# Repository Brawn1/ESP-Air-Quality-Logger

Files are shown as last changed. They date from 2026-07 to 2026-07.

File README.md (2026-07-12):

# Raumluft-Qualität-Messung (ESP32-S3-Zero)

CO₂-, Temperatur- und Feuchte-Messung mit dem **SCD30**, Anzeige auf einem
**0,96" OLED**, Status-Anzeige über eine **WS2812B-LED-Ampel**, Uhrzeit von
einer **DS3231-RTC** (mit NTP-Abgleich), Datenlogging auf **MicroSD** und einem
**WLAN-Webinterface**, dessen statische Dateien von der SD-Karte ausgeliefert
werden.

Die Firmware läuft unter **FreeRTOS** und verteilt die Arbeit auf beide Kerne
des ESP32-S3.

---

## Funktionen

- **Messung** von CO₂ / Temperatur / Luftfeuchte (SCD30, NDIR-Sensor)
- **OLED-Anzeige**: Uhrzeit, IP-Adresse, Messwerte groß + Ampel-Bewertung
- **LED-Ampel** (WS2812B): grün/orange/rot je nach CO₂, gut ablesbar quer durch den Raum
- **Weboberfläche** (responsiv, ohne externe Bibliotheken) mit Live-Werten und
  Verlaufsgraph (CO₂ / Temp / Feuchte umschaltbar)
- **Datenlogging** als Tages-CSV auf SD; Verlauf übersteht Neustart (`/history.json`)
- **Uhrzeit** aus DS3231-RTC, automatischer **NTP-Abgleich** bei WLAN-Verbindung
- **WLAN**: Verbindung ins Heimnetz, bei Fehlschlag eigener **Access-Point-Fallback**
- **Manuelle Kalibrierung** des SCD30 per BOOT-Taster (Forced Recalibration)

---

## Architektur (FreeRTOS, Dual-Core)

| Task | Kern | Prio | Aufgabe |
|---|:----:|:----:|---|
| `SensorTask`  |  1 |  3 | SCD30 lesen, Live-Wert/Verlauf/LED-Ampel, Logs auslösen, BOOT-Taster |
| `DisplayTask` |  1 |  2 | OLED zeichnen (Uhr, IP, Werte, Bewertung) |
| `LoggerTask`  |  1 |  2 | SD-Aufträge abarbeiten (CSV + `/history.json`) |
| `NetworkTask` |  0 |  1 | WLAN (STA + AP-Fallback), NTP, Webserver-Verwaltung |
| AsyncTCP |  0 |  – | Webserver-Requests (von der Bibliothek verwaltet) |

**Geteilte Busse werden per Mutex serialisiert** (nicht thread-safe):

- `g_i2cMutex` – **I²C** (SCD30 + DS3231), Zugriffe aus Tasks beider Kerne
- `g_spiMutex` – **SD-SPI-Bus** (Logger schreibt, Webserver liest)
- Daten-Mutex im `Data`-Modul – geteilter Zustand (Live-Wert + Verlaufs-Ringpuffer)
- Das **OLED** liegt auf einem **eigenen HSPI-Bus** (nur `DisplayTask`) → kein Mutex nötig

Datenfluss: `SensorTask` → (RAM-Ringpuffer + Queue) → `LoggerTask` (SD) /
`DisplayTask` (OLED) / Web-API (RAM).

---

## Verdrahtung (bitte gegen den Aufdruck deines Boards prüfen!)

### I²C-Bus – SCD30 und DS3231-RTC
| Signal | ESP32-S3-Zero |
|---|---|
| SDA | GPIO8 |
| SCL | GPIO9 |
| VCC | 3V3 (SCD30 verträgt 5V am VIN, Logik bleibt 3V3) |
| GND | GND |

> Beide I²C-Geräte an **denselben** SDA/SCL. Der SCD30 nutzt Clock-Stretching;
> deshalb ist der I²C-Takt bewusst auf 100 kHz gesetzt. Pull-ups (4,7 kΩ) sind
> auf den Modulen meist vorhanden.

### SPI-Bus 1 (FSPI) – nur MicroSD
| Signal | ESP32-S3-Zero |
|---|---|
| SCK | GPIO12 |
| MOSI | GPIO11 |
| MISO | GPIO13 |
| CS | GPIO10 |
| VCC / GND | 3V3 / GND  |

### SPI-Bus 2 (HSPI) – nur SSD1306-OLED (**eigener** Bus!)
SD und OLED **dürfen sich den SPI-Bus nicht teilen**: Die ESP32-`SD.h` nutzt den
IDF-`sdspi`-Treiber und belegt den SPI-Host exklusiv – ein zweites Gerät am
selben Bus bleibt stumm. Deshalb hat das OLED einen eigenen Bus.

| OLED-Pin (7-polige SPI-Platine) | ESP32-S3-Zero |
|---|---|
| D0 (CLK/SCK) | GPIO7 |
| D1 (DATA/MOSI) | GPIO1 |
| DC | GPIO4 |
| RES | GPIO6 |
| CS | GPIO5 |
| VCC / GND | 3V3 / GND |

**Alternative: I²C-OLED (4-polig)** – falls du ein SSD1306/SH1106 mit I²C statt SPI
hast, in `config.h` `#define OLED_USE_I2C 1` setzen. Das OLED läuft dann auf einem
**eigenen, zweiten I²C-Bus** (der ESP32-S3 hat zwei) — getrennt vom SCD30/RTC-Bus,
daher **kein Mutex nötig**. Praktisch: Es werden **dieselben Pins wie beim SPI-D0/D1**
verwendet, du musst also nichts umverdrahten:

| I²C-OLED-Pin | ESP32-S3-Zero | (= SPI-Pin) |
|---|---|---|
| SCL | GPIO7 | D0 |
| SDA | GPIO1 | D1 |
| VCC / GND | 3V3 / GND | – |

(Pins `PIN_OLED_I2C_SCL`/`PIN_OLED_I2C_SDA`, Adresse `OLED_I2C_ADDR` meist `0x3C`,
kein Reset-Pin nötig. Bus läuft mit 400 kHz.)

### WS2812B-Statusstreifen (CO₂-Ampel)
| Streifen | ESP32-S3-Zero |
|---|---|
| DIN (Pfeilrichtung beachten!) | GPIO2 (alt. GPIO1) |
| 5V | 5V |
| GND | GND |

> **GPIO3 meiden** (Strapping-Pin). Die LEDs (`NUM_STATUS_LEDS`, Standard 4) sind auf `LED_BRIGHTNESS = 30/255`
> gedimmt (Strom/Blendung); bei langen/hellen Streifen externes 5V-Netzteil mit
> gemeinsamer GND. Kurze Streifen laufen meist direkt mit dem 3,3-V-Datensignal,
> sonst Pegelwandler (3,3→5 V).

### BOOT-Taster
Der Onboard-**BOOT-Taster (GPIO0)** dient im Betrieb zum Auslösen der
Kalibrierung (siehe unten). Ruhezustand HIGH, gedrückt LOW.

### Pin-Übersicht
| Pin | Funktion | Pin | Funktion |
|-----|---|-----|---|
| GPIO8  | I²C SDA | GPIO7 | OLED SCK (D0) |
| GPIO9  | I²C SCL | GPIO1 | OLED MOSI (D1) |
| GPIO12 | SD SCK | GPIO4 | OLED DC |
| GPIO11 | SD MOSI | GPIO6 | OLED RES |
| GPIO13 | SD MISO | GPIO5 | OLED CS |
| GPIO10 | SD CS | GPIO2 | WS2812B DIN |
| GPIO0  | BOOT-Taster | | |

Alle Pins zentral in [`code/config.h`](code/config.h) änderbar.

---

## Projektstruktur

```
code/                 ← Arduino-Sketch (alle Dateien gehören dazu)
  code.ino            Setup + FreeRTOS-Tasks
  config.h            Pins, Intervalle, Schwellen, Task-Konfiguration
  Sync.*              geteilter SPI-Bus + Mutexe (I²C / SPI)
  Data.*              thread-sicherer Ringpuffer + Live-Wert + Status
  Sensor.*            SCD30 (Sensirion I2C SCD30)
  AppTime.*           DS3231-RTC + NTP
  Storage.*           SD: config.json, CSV, history.json, Datei-Auslieferung
  Display.*           OLED (SSD1306 / SH1106 umschaltbar)
  Led.*               WS2812B-CO₂-Ampel
  WebNet.*            WLAN (STA/AP), NTP-Start, Async-Webserver
sd_card/              ← Inhalt auf die SD-Karten-Wurzel kopieren
  config.json         WLAN + Einstellungen
  www/                Weboberfläche (index.html, style.css, app.js)
README.md
```

---

## Benötigte Arduino-Bibliotheken

Über den **Bibliotheksverwalter** installieren:

- **Sensirion I2C SCD30** (zieht *Sensirion Core* mit)
- **Adafruit SSD1306** + **Adafruit GFX Library**
- **Adafruit SH110X** (nur nötig, wenn `OLED_USE_SH1106 = 1`)
- **RTClib** (Adafruit)
- **Adafruit NeoPixel**
- **ArduinoJson** (v7)
- **Async TCP** *(Maintainer: ESP32Async, v3.4.x)*
- **ESP Async WebServer** *(Maintainer: ESP32Async, v3.11.x)*

> ⚠️ **Richtigen Async-Fork wählen!** Es gibt mehrere gleichnamige Bibliotheken.
> Es funktionieren **nur** die von **ESP32Async** gepflegten, exakt benannt
> **„Async TCP"** und **„ESP Async WebServer"** (mit Leerzeichen). Die Varianten
> `AsyncTCP` (dvarrel) bzw. `ESPAsyncWebServer` (lacamera) sind mit ESP32-Core 3.x
> **nicht** kompatibel (Compile-Fehler in `WiFiGeneric.h`).

`WiFi`, `SD`, `SPI`, `Wire`, `ESPmDNS` sind Teil des ESP32-Arduino-Cores.

### Board / Core
- Boardverwalter-URL für ESP32 hinzufügen, **esp32 by Espressif** (Core **3.x**) installieren.
- Board: **ESP32S3 Dev Module** (oder „Waveshare ESP32-S3-Zero", falls vorhanden).
- **PSRAM**: „QSPI/OPI PSRAM" aktivieren, falls dein Modul PSRAM hat (sonst „Disabled").
- **USB CDC On Boot: Enabled** (für die serielle Ausgabe über USB-C).
- **Partition Scheme: „Huge APP (3MB No OTA/1MB SPIFFS)"** – reichlich Reserve
  (SPIFFS wird nicht gebraucht, alles liegt auf der SD).

---

## Einrichtung

1. **SD-Karte** (FAT32) vorbereiten und den **Inhalt** von [`sd_card/`](sd_card/)
   in das **Wurzelverzeichnis** kopieren:
   ```
   SD-Root/
     config.json
     www/
       index.html
       style.css
       app.js
   ```
2. In `config.json` **WLAN-Zugangsdaten** und ggf. Zeitzone/Intervalle eintragen.
   - Leeres `wifi_ssid` → Gerät startet direkt im **Access-Point-Modus**.
   - Fehlschlagende WLAN-Verbindung → automatischer AP `Raumluft-Sensor`
     (Passwort `raumluft1234`).
3. Sketch [`code/code.ino`](code/code.ino) in der Arduino IDE öffnen, Board wählen,
   **hochladen**.
4. Serielle Konsole (115200 Baud) zeigt die zugewiesene **IP-Adresse**.
   Aufruf im Browser: `http://<IP>` oder `http://raumluft.local`.

---

## Konfiguration (`config.json`)

Alle Werte werden **zur Laufzeit** von der SD geladen; die Konstanten in
`config.h` sind nur die Fallback-Defaults, falls die Datei fehlt.

| Schlüssel | Standard | Bedeutung |
|---|---|---|
| `wifi_ssid` | – | WLAN-Name (leer = direkt AP-Modus) |
| `wifi_pass` | – | WLAN-Passwort |
| `ap_ssid` | `Raumluft-Sensor` | Name des Fallback-Access-Points |
| `ap_pass` | `raumluft1234` | AP-Passwort (≥8 Zeichen, "" = offen) |
| `hostname` | `raumluft` | mDNS-Name → `http://raumluft.local` |
| `ntp_server` | `pool.ntp.org` | NTP-Server |
| `tz` | `CET-1CEST,M3.5.0,M10.5.0/3` | Zeitzone (POSIX-TZ) |
| `scd30_interval_s` | `5` | Mess-Takt des Sensors (2…1800 s) |
| `history_interval_s` | `90` | Graph-Punkt + `/history.json` schreiben |
| `log_interval_s` | `300` | CSV-Archiv-Takt (s) |
| `temp_offset_c` | `3.0` | Temperatur-Offset (°C), per Software abgezogen: Anzeige = Messwert − Offset (auch negativ) |

> ⚠️ **JSON-Schlüssel sind Groß-/Kleinschreibung-sensitiv** – exakt so schreiben,
> sonst wird der Eintrag still ignoriert und der Standardwert genutzt.

---

## Bedienung

### OLED-Anzeige
```
12:34:56              WiFi   ← Uhrzeit + Netz-Kennung (WiFi/AP)
192.168.1.42     kein SD     ← IP (STA/AP); rechts "kein SD" falls Karte fehlt
612          ppm             ← CO₂ groß
T 22.8C  H 45%               ← Temperatur / Feuchte
OK                           ← Bewertung: OK / Lueften empf. / Raum lueften
```

Fehlt/defekt die SD-Karte, zeigt das Display beim Start einen Warn-Screen
(„KEINE SD-KARTE") und dauerhaft den Hinweis **`kein SD`** neben der IP. Die
Karte wird **im Betrieb überwacht** (alle ~5 s): Herausziehen wird erkannt und
angezeigt, Wiedereinstecken automatisch übernommen. (Ohne SD gibt es kein
Webinterface, da dessen Dateien auf der Karte liegen.)

### LED-Ampel (WS2812B)
Alle LEDs (`NUM_STATUS_LEDS`, Standard 4) leuchten gemeinsam in der Ampelfarbe des
aktuellen CO₂-Werts:
**grün ≤ 1000 (OK) → orange ≤ 1400 (Lüften empfohlen) → rot > 1400 (Raum lüften).**
Kein Messwert → blau.

### Weboberfläche
Live-Werte (Polling), umschaltbarer Verlaufsgraph (CO₂ / Temp / Feuchte) und
Statusleiste (WLAN, SD, RTC/NTP). Die statischen Dateien werden im Browser
gecacht – nach dem ersten Laden werden bei Reload nur noch die kleinen
`/api/*`-Aufrufe geholt (schont Verbindungen).

---

## Web-API

| Endpoint | Antwort |
|---|---|
| `GET /api/current` | aktueller Messwert + Status (JSON) |
| `GET /api/history` | letzte 30 Verlaufspunkte (JSON, aus RAM) |
| alles andere | statische Datei aus `/www` auf der SD |

Beispiel `/api/current`:
```json
{"time":1751385600,"co2":612,"temp":22.80,"hum":47.0,"valid":true,
 "wifi":true,"ap":false,"ip":"192.168.1.42","ssid":"MeinWLAN",
 "rtc":true,"sd":true,"synced":true}
```

---

## Dateien auf der SD-Karte

| Pfad | Inhalt |
|---|---|
| `/config.json` | Konfiguration (s. o.) |
| `/www/…` | Weboberfläche (HTML/CSS/JS) |
| `/history.json` | letzte 30 Verlaufspunkte – wird alle `history_interval_s` geschrieben und beim Booten geladen (Graph sofort gefüllt) |
| `/logs/JJJJ-MM-TT.csv` | Langzeit-Archiv, eine Zeile je `log_interval_s` |

CSV-Format:
```
epoch_utc,datetime_local,co2_ppm,temp_c,hum_pct
```

---

## Kalibrierung (BOOT-Taster)

Der SCD30 lässt sich per **Forced Recalibration (FRC)** über den **BOOT-Taster
(GPIO0)** auf einen Frischluft-Referenzwert setzen (`CO2_CALIBRATION_PPM`,
Standard **420 ppm** ≈ heutige Außenluft).

1. Gerät im Betrieb an **gut durchmischte Frischluft** bringen (draußen / offenes
   Fenster mit Durchzug), Sensor **frei halten, nicht bodennah**.
2. **~2 Minuten** messen lassen, damit der Wert stabil ist.
3. **BOOT-Taster ca. 3 Sekunden halten** (`CAL_HOLD_MS`).
4. Bestätigung: LED-Streifen blinkt **3× grün** (und OLED-Meldung, falls aktiv).

**Wichtig:**
- Taster nur **im Betrieb** drücken – *nicht* beim Reset/Einschalten (sonst geht
  der ESP32 in den Download-Modus).
- **Abends auf dem Land ungünstig:** windstille Abende stauen bodennah CO₂ →
  besser tagsüber bei etwas Wind.
- Eine falsche Referenz verzieht die Werte dauerhaft, lässt sich aber jederzeit
  mit besserer Frischluft neu kalibrieren.

> Alternativ gibt es die automatische Selbstkalibrierung (ASC) des SCD30. Sie ist
> **aus**; bei Dauerbetrieb in regelmäßig gelüfteten Räumen kann sie in
> `sensorBegin()` per `activateAutoCalibration(1)` eingeschaltet werden.

---

## Hinweise / Tuning / Troubleshooting

- **OLED bleibt dunkel?** SD und OLED **nicht** an denselben SPI-Bus hängen (s. o.).
  Bleibt es auf dem eigenen HSPI-Bus *immer noch* leer, ist es evtl. ein
  **SH1106**-Controller statt SSD1306. Umschalter in `config.h`:
  ```c
  #define OLED_USE_SH1106 1   // 0 = SSD1306, 1 = SH1106 (Adafruit SH110X)
  ```
- **OLED zu dunkel / ungleichmäßig?** Kontrast steht bereits auf `OLED_CONTRAST = 255`,
  Precharge (`OLED_PRECHARGE`, SSD1306) lässt sich Richtung `0xFF` anheben. Eine
  weiche Rand-Abdunklung ist meist eine Eigenschaft des Panels selbst.
- **Verlauf übersteht Neustart** über `/history.json` (Laden beim Booten). Die
  laufende `/api/history` bleibt reines RAM (schnell), das CSV ist das Archiv.
- **WLAN nur 2,4 GHz:** Der ESP32 verbindet sich nicht mit 5-GHz-Netzen. Klappt
  die STA-Verbindung nicht, läuft das Gerät im AP-Modus (`192.168.4.1`), und ohne
  Internet gibt es keinen NTP-Sync (Zeit dann rein aus der DS3231).
- **Webserver reagiert nach mehreren Verbindungen nicht mehr?** Diagnose über die
  serielle Heap-Ausgabe (alle 30 s): fällt „Heap frei" stetig → Speicher; bleibt
  er stabil → Verbindungs-Slots. Das Caching der statischen Dateien reduziert die
  Last bereits deutlich; bei Bedarf Poll-Intervall in `app.js` strecken.
- **SD-Takt:** Bei instabilen Karten in `Storage.cpp` von `20000000` auf `4000000`
  (4 MHz) reduzieren.
- **RTC erstmalig stellen:** passiert automatisch beim ersten erfolgreichen
  NTP-Sync. Ohne Internet läuft die Zeit rein aus der DS3231.

### Modul-Namen (Fallstricke)
Das Netzwerkmodul heißt bewusst `WebNet.*` (nicht `Network.*`) und die
LED-Konstante `PIN_STATUS_LED` (nicht `PIN_RGB_LED`) – beide Namen sind im
ESP32-Core/S3-Variant bereits belegt und würden sonst Compile-Fehler auslösen.

---

## Lizenz

Copyright (C) 2026 Guenter Bailey

Dieses Projekt steht unter der **GNU Affero General Public License v3.0**
(AGPL-3.0) – siehe [LICENSE](LICENSE).

> Dieses Programm ist freie Software: Sie können es unter den Bedingungen der
> AGPL-3.0 weitergeben und/oder verändern. Es wird **ohne jede Gewährleistung**
> bereitgestellt; siehe die Lizenz für Details. Sie sollten eine Kopie der Lizenz
> zusammen mit diesem Programm erhalten haben. Falls nicht, siehe
> <https://www.gnu.org/licenses/>.

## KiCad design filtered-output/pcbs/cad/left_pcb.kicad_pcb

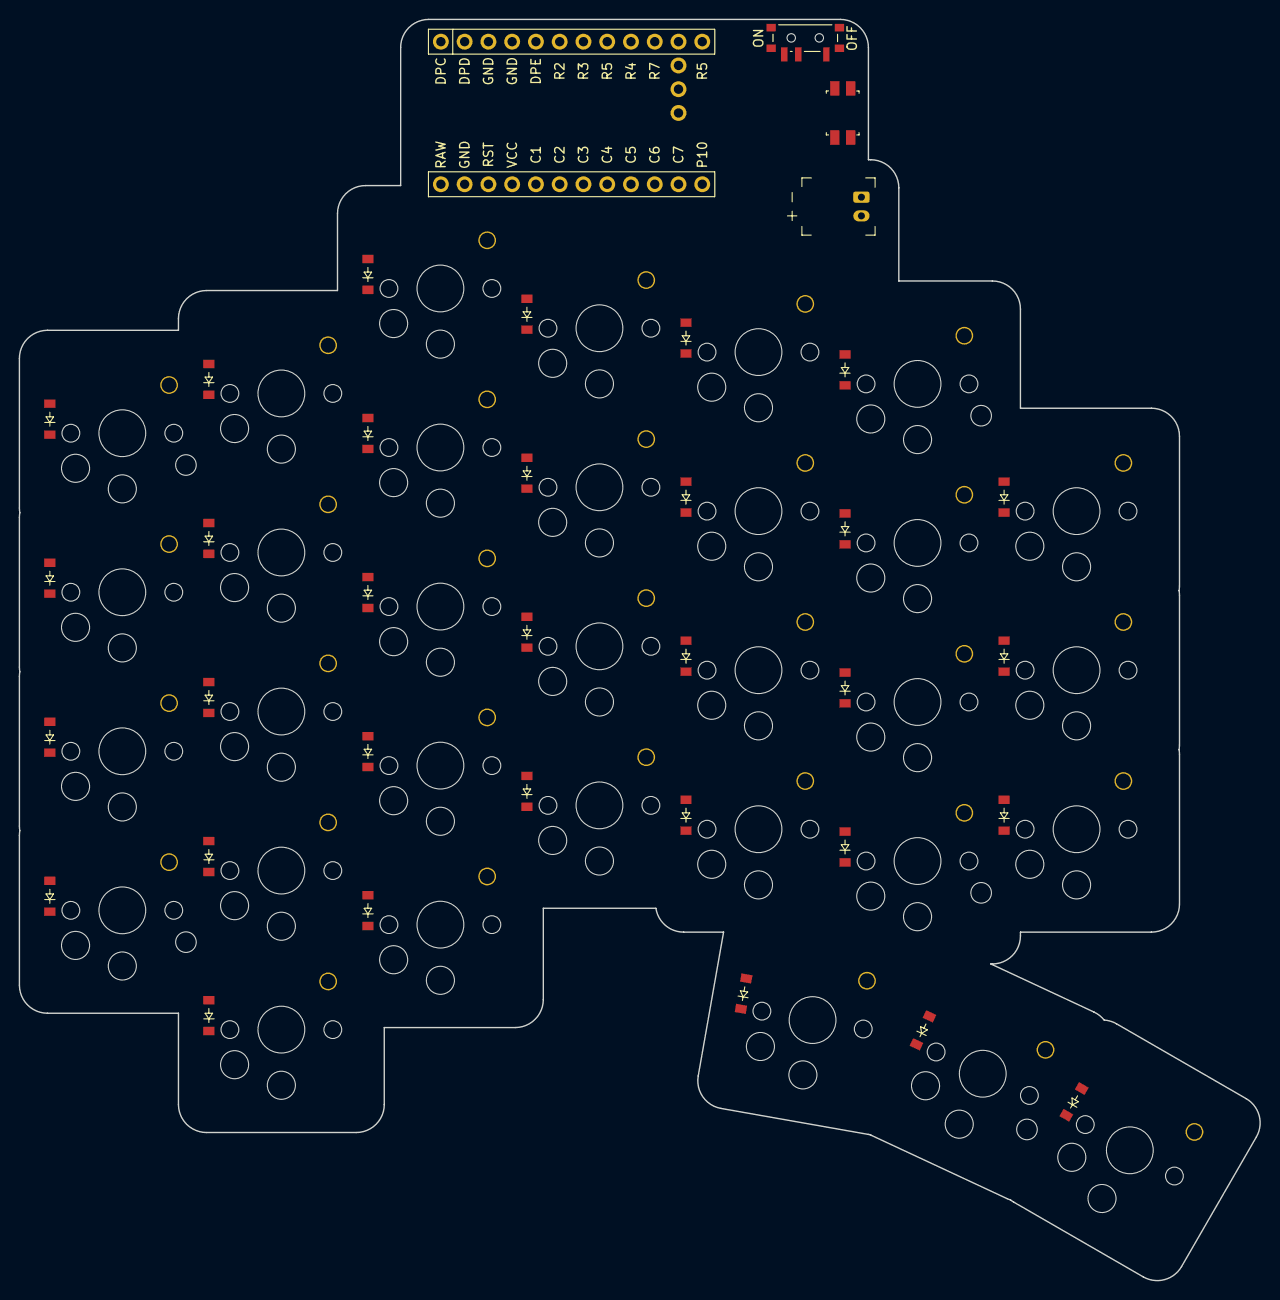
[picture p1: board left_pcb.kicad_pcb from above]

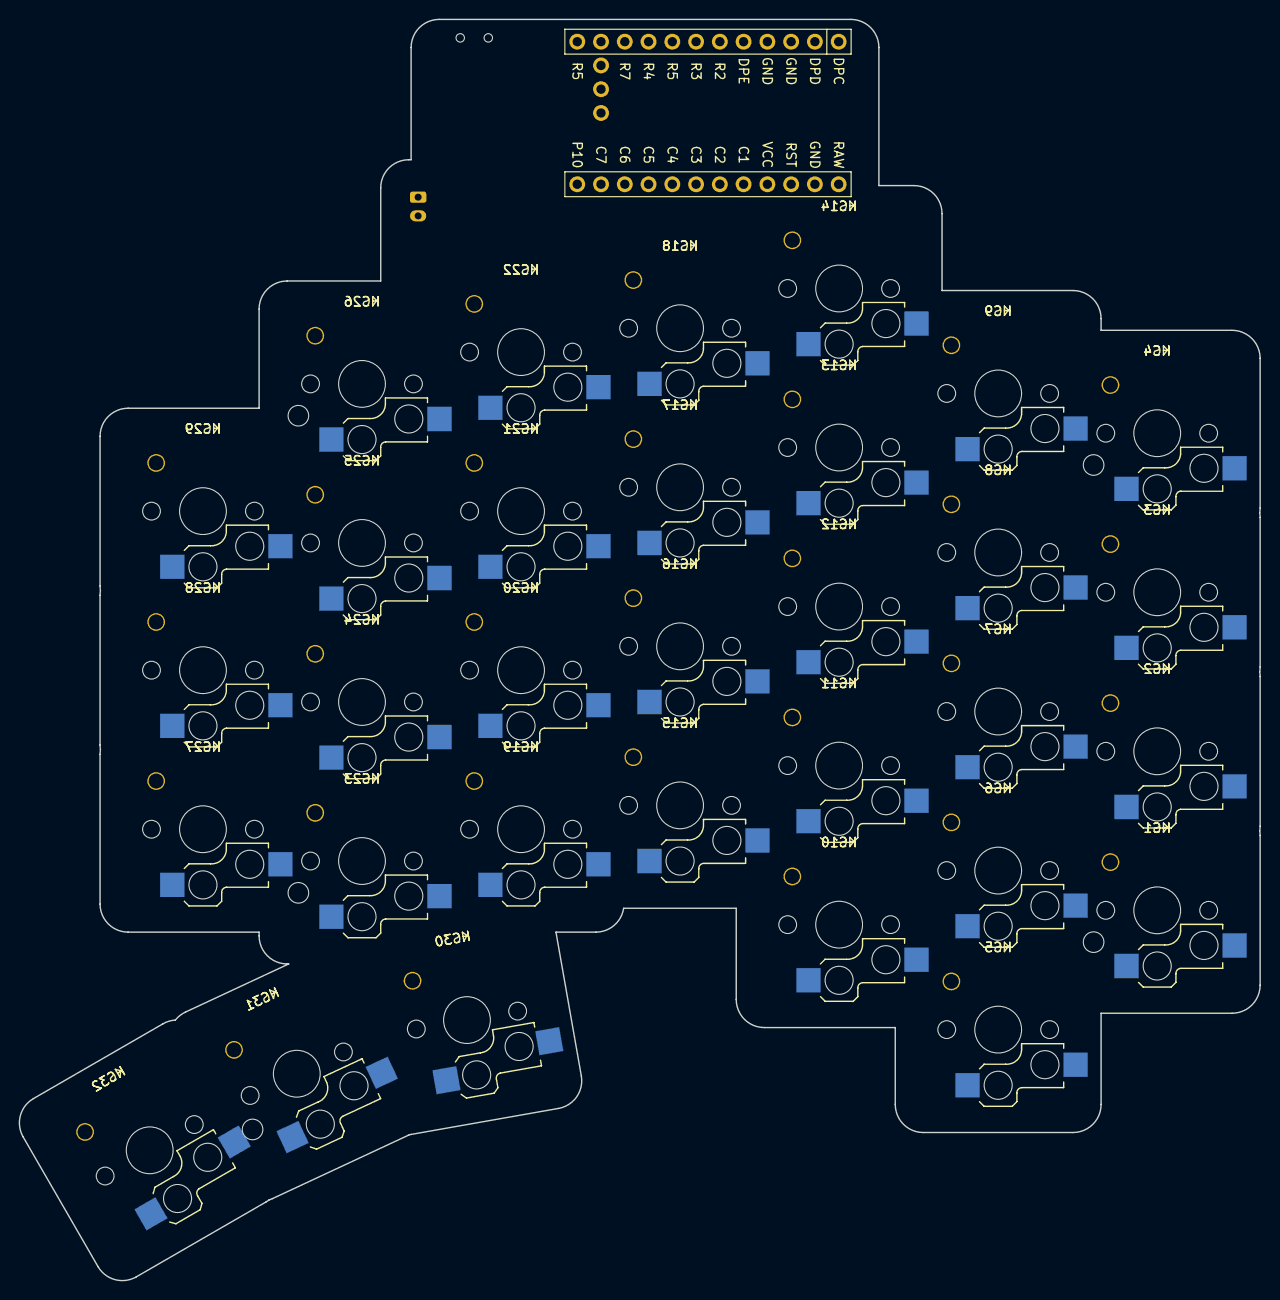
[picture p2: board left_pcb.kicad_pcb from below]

Board: 2 copper layers, 132.6 x 134.8 mm, 154 parts (96 on the bottom side), 48 nets, no tracks yet.

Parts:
D1, D2, D3, D4, D5, D6, D7, D8, D9, D10, D11, D12, D13, D14, D15, D16, D17, D18, D19, D20, D21, D22, D23, D24, D25, D26, D27, D28, D29, D30, D31, D32: diode_tht_sod123
H1, H2: header-preview_nano
HS1, HS2, HS3, HS4, HS5, HS6, HS7, HS8, HS9, HS10, HS11, HS12, HS13, HS14, HS15, HS16, HS17, HS18, HS19, HS20, HS21, HS22, HS23, HS24, HS25, HS26, HS27, HS28, HS29, HS30, HS31, HS32: hs-socket-fab-preview_choc_v1_v2
JST1: battery_connector_jst_ph_2
KC1, KC2, KC3, KC4, KC5, KC6, KC7, KC8, KC9, KC10, KC11, KC12, KC13, KC14, KC15, KC16, KC17, KC18, KC19, KC20, KC21, KC22, KC23, KC24, KC25, KC26, KC27, KC28, KC29, KC30, KC31, KC32: keycap-fab-preview_choc_v1_v2
MCU1: mcu_nice_nano
MH1, MH2, MH3, MH4, MH5: mounting_hole_npth
PWR1: power_switch_smd_side
RST1: reset_switch_smd_side
S1, S2, S3, S4, S5, S6, S7, S8, S9, S10, S11, S12, S13, S14, S15, S16, S17, S18, S19, S20, S21, S22, S23, S24, S25, S26, S27, S28, S29, S30, S31, S32: choc_v1_v2
SC1, SC2, SC3, SC4, SC5: screw-preview-top
SC6, SC7, SC8, SC9, SC10: screw-preview-bottom
ST1, ST2, ST3, ST4, ST5: standoff-preview

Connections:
BAT_P: JST1.2, PWR1.3
C1: MCU1.20, S1.2, S2.2, S3.2, S4.2
C2: MCU1.19, S5.2, S6.2, S7.2, S8.2, S9.2
C3: MCU1.18, S10.2, S11.2, S12.2, S13.2, S14.2
C4: MCU1.17, S15.2, S16.2, S17.2, S18.2
C5: MCU1.16, S19.2, S20.2, S21.2, S22.2, S30.2
C6: MCU1.15, S23.2, S24.2, S25.2, S26.2, S31.2
C7: MCU1.14, S27.2, S28.2, S29.2, S32.2
GND: JST1.1, MCU1.3, MCU1.4, MCU1.23, RST1.1, RST1.3
R1: D4.1, D9.1, D14.1, D18.1, D22.1, D26.1
R2: D3.1, D8.1, D13.1, D17.1, D21.1, D25.1, D29.1, MCU1.6
R3: D2.1, D7.1, D12.1, D16.1, D20.1, D24.1, D28.1, MCU1.7
R4: D1.1, D6.1, D11.1, D15.1, D19.1, D23.1, D27.1, MCU1.9
R5: D5.1, D10.1, D30.1, D31.1, D32.1, MCU1.8, MCU1.12
RAW: MCU1.24, PWR1.2
RST: MCU1.22, RST1.2, RST1.4
col1_row1: D4.2, S4.1
col1_row2: D3.2, S3.1
col1_row3: D2.2, S2.1
col1_row4: D1.2, S1.1
col1_thumb_row_1: D30.2, S30.1
col2_row1: D9.2, S9.1
col2_row2: D8.2, S8.1
col2_row3: D7.2, S7.1
col2_row4: D6.2, S6.1
col2_row5: D5.2, S5.1
col2_thumb_row_1: D31.2, S31.1
col3_row1: D14.2, S14.1
col3_row2: D13.2, S13.1
col3_row3: D12.2, S12.1
col3_row4: D11.2, S11.1
col3_row5: D10.2, S10.1
col3_thumb_row_1: D32.2, S32.1
col4_row1: D18.2, S18.1
col4_row2: D17.2, S17.1
col4_row3: D16.2, S16.1
col4_row4: D15.2, S15.1
col5_row1: D22.2, S22.1
col5_row2: D21.2, S21.1
col5_row3: D20.2, S20.1
col5_row4: D19.2, S19.1
col6_row1: D26.2, S26.1
col6_row2: D25.2, S25.1
col6_row3: D24.2, S24.1
col6_row4: D23.2, S23.1
col7_row2: D29.2, S29.1
col7_row3: D28.2, S28.1
col7_row4: D27.2, S27.1

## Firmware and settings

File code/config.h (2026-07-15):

// ============================================================================
//  config.h  -  Zentrale Konfiguration & gemeinsame Datentypen
//  Projekt: Raumluft-Qualitaet-Messung (ESP32-S3-Zero)
// ============================================================================
#pragma once
#include <Arduino.h>

// ----------------------------------------------------------------------------
//  PIN-BELEGUNG  (ESP32-S3-Zero / Waveshare)
//  -> Bitte gegen den Aufdruck deines Boards pruefen und ggf. anpassen.
//
//  I2C-Bus (gemeinsam fuer SCD30-Sensor und DS3231-RTC):
//     SDA = GPIO8      SCL = GPIO9
//
//  SPI-Bus 1 (FSPI) - NUR MicroSD:
//     SCK = GPIO12   MOSI = GPIO11   MISO = GPIO13   SD-CS = GPIO10
//  SPI-Bus 2 (HSPI) - NUR SSD1306-OLED (eigener Bus, damit kein Konflikt mit
//                     dem IDF-sdspi-Treiber der SD-Karte entsteht):
//     SCK = GPIO7   MOSI = GPIO1   DC = GPIO4   RST = GPIO6   CS = GPIO5
//     (OLED hat kein MISO - Display ist reines Schreibziel)
//
//  WS2812B-Statusstreifen (CO2-Balken), Daten-Pin (DIN): GPIO2
//  (GPIO1 oder GPIO2 verwenden; GPIO3 meiden = Strapping-Pin.
//   Hinweis: NICHT 'PIN_RGB_LED' verwenden - dieser Name ist im S3-Variant
//   bereits als Makro belegt.)
// ----------------------------------------------------------------------------
static const int PIN_I2C_SDA = 8;
static const int PIN_I2C_SCL = 9;

// SD-Bus (FSPI)
static const int PIN_SPI_MOSI = 11;
static const int PIN_SPI_SCK  = 12;
static const int PIN_SPI_MISO = 13;
static const int PIN_SD_CS    = 10;

// SD-SPI-Takt in Hz. Niedriger = robuster (v.a. bei grossen SDXC-Karten / langen
// Leitungen). 4 MHz ist sehr zuverlaessig; unsere Datenmengen sind winzig.
static const uint32_t SD_SPI_HZ = 4000000;

// OLED-Bus (HSPI, eigener Bus)
static const int PIN_OLED_SCK  = 7;
static const int PIN_OLED_MOSI = 1;
static const int PIN_OLED_DC   = 4;
static const int PIN_OLED_RST  = 6;
static const int PIN_OLED_CS   = 5;

static const int PIN_STATUS_LED = 2;    // WS2812B-Streifen DIN; -1 = deaktiviert

static const int PIN_BOOT_BUTTON = 0;   // Onboard-BOOT-Taster (GPIO0, active low)

// ----------------------------------------------------------------------------
//  OLED-Geometrie (0,96" SSD1306)
// ----------------------------------------------------------------------------
static const int OLED_WIDTH  = 128;
static const int OLED_HEIGHT = 64;

// OLED-Controller waehlen:  0 = SSD1306,  1 = SH1106 (Adafruit SH110X)
// -> Zum Testen des anderen Display-Typs einfach umschalten und neu flashen.
#define OLED_USE_SH1106 0

// OLED-Anbindung waehlen:  0 = SPI (7-polig, eigener HSPI-Bus),
//                          1 = I2C auf EIGENEM 2. Bus (Wire1) an den Display-Pins
// Bei I2C wird ein separater I2C-Bus genutzt (NICHT der SCD30/RTC-Bus) -> keine
// Umverdrahtung noetig, kein Mutex. Die Display-Pins bleiben GPIO7/GPIO1:
//   GPIO7 (= D0 am Display) = SCL,  GPIO1 (= D1 am Display) = SDA
#define OLED_USE_I2C 1

static const uint8_t OLED_I2C_ADDR   = 0x3C;   // meist 0x3C, manche Module 0x3D
static const int     PIN_OLED_I2C_SCL = 7;     // = D0 am Display (GPIO7)
static const int     PIN_OLED_I2C_SDA = 1;     // = D1 am Display (GPIO1)

// Helligkeit/Kontrast des OLED (0..255). 255 = maximal hell.
static const uint8_t OLED_CONTRAST = 100;

// Precharge-Periode (Befehl 0xD9): High-Nibble = Phase 2, Low-Nibble = Phase 1
// (je 1..15 Takte). Laenger = heller/gleichmaessiger. Adafruit-Default 0xF1.
// Zum Aufhellen v.a. das Low-Nibble (Phase 1) anheben, bis max. 0xFF.
static const uint8_t OLED_PRECHARGE = 0xF1;

// ----------------------------------------------------------------------------
//  Mess- & Logintervalle
// ----------------------------------------------------------------------------
// Drei getrennte Kadenzen (alle zur Laufzeit ueber config.json ueberschreibbar):
static const uint32_t SCD30_INTERVAL_S   = 8;    // Sensor-Messintervall (2..1800 s)
static const uint32_t HISTORY_INTERVAL_S = 90;   // Graph-Punkt + /history.json schreiben
static const uint32_t LOG_INTERVAL_S     = 300;  // CSV-Archiv (5 min)

// Anzahl der Punkte im Verlaufsgraphen (RAM-Ringpuffer + /history.json).
static const int HISTORY_LEN = 30;

// ----------------------------------------------------------------------------
//  CO2-Ampel-Schwellen (ppm)
// ----------------------------------------------------------------------------
static const uint16_t CO2_GOOD_MAX    = 1000;   // <= gruen (OK)
static const uint16_t CO2_MEDIUM_MAX  = 1400;   // <= orange (Lueften empf.), darueber rot

// ----------------------------------------------------------------------------
//  Manuelle Kalibrierung (Forced Recalibration) per BOOT-Taster
// ----------------------------------------------------------------------------
static const uint16_t CO2_CALIBRATION_PPM = 420;    // Referenz = Frischluft (akt. Atmosphaere ~420 ppm)
static const uint32_t CAL_HOLD_MS         = 3000;   // Taster so lange halten

// ----------------------------------------------------------------------------
//  Temperatur-Offset (SCD30 misst durch Eigenerwaermung zu hoch)
//  Wird per Software vom Messwert abgezogen: angezeigt = gemessen - Offset.
//  Positiv = Anzeige senken (Normalfall), negativ = anheben moeglich.
// ----------------------------------------------------------------------------
static const float TEMP_OFFSET_C = 3.0f;

// ----------------------------------------------------------------------------
//  WS2812B-Statusstreifen als CO2-Ampel (alle LEDs = Ampelfarbe)
// ----------------------------------------------------------------------------
static const int      NUM_STATUS_LEDS = 1;      // Anzahl LEDs am Streifen (bei neuem Streifen hier erhoehen)
static const uint8_t  LED_BRIGHTNESS  = 30;     // 0..255 (gedimmt, spart Strom)

// ----------------------------------------------------------------------------
//  WLAN / Netzwerk  (Standardwerte; werden von /config.json auf der SD ueberschrieben)
// ----------------------------------------------------------------------------
#define DEFAULT_WIFI_SSID     ""            // dein Heim-WLAN
#define DEFAULT_WIFI_PASS     ""
#define DEFAULT_AP_SSID       "Raumluft-Sensor"
#define DEFAULT_AP_PASS       "raumluft1234"  // min. 8 Zeichen (WPA2), "" = offen
#define DEFAULT_HOSTNAME      "raumluft"

// NTP / Zeitzone (Standard: Mitteleuropa mit Sommerzeit)
#define DEFAULT_NTP_SERVER    "pool.ntp.org"
#define DEFAULT_TZ            "CET-1CEST,M3.5.0,M10.5.0/3"

// ----------------------------------------------------------------------------
//  Gemeinsamer Datentyp fuer einen Messpunkt
// ----------------------------------------------------------------------------
struct Sample {
  uint32_t epoch;   // Unix-Zeit (Sekunden) laut RTC
  float    co2;     // ppm
  float    temp;    // Grad Celsius
  float    hum;     // % relative Feuchte
  uint32_t heap;    // freier Heap (Bytes) zum Messzeitpunkt - Diagnose
  bool     valid;
};

// ----------------------------------------------------------------------------
//  Laufzeit-Konfiguration (aus /config.json geladen)
// ----------------------------------------------------------------------------
struct AppConfig {
  String wifiSsid   = DEFAULT_WIFI_SSID;
  String wifiPass   = DEFAULT_WIFI_PASS;
  String apSsid     = DEFAULT_AP_SSID;
  String apPass     = DEFAULT_AP_PASS;
  String hostname   = DEFAULT_HOSTNAME;
  String ntpServer  = DEFAULT_NTP_SERVER;
  String tz         = DEFAULT_TZ;
  uint32_t logIntervalS     = LOG_INTERVAL_S;      // CSV-Archiv-Takt (s)
  uint32_t historyIntervalS = HISTORY_INTERVAL_S;  // Graph-/History-Takt (s)
  uint32_t scd30IntervalS   = SCD30_INTERVAL_S;    // SCD30-Mess-Takt (s, 2..1800)
  float    tempOffsetC      = TEMP_OFFSET_C;       // Temperatur-Offset (Grad C)
};

extern AppConfig g_cfg;

// ----------------------------------------------------------------------------
//  FreeRTOS-Task-Konfiguration
//  ESP32-S3 = Dual-Core:  Core 0 = Netzwerk, Core 1 = Messung/Anzeige
// ----------------------------------------------------------------------------
static const BaseType_t CORE_MEASURE = 1;   // Messkern
static const BaseType_t CORE_NETWORK = 0;   // Netzwerkkern

// Stackgroessen (Bytes) und Prioritaeten (hoeher = wichtiger, IDLE = 0)
static const uint32_t STACK_SENSOR  = 4096;
static const uint32_t STACK_DISPLAY = 4096;
static const uint32_t STACK_LOGGER  = 4096;
static const uint32_t STACK_NETWORK = 8192;

static const UBaseType_t PRIO_SENSOR  = 3;
static const UBaseType_t PRIO_DISPLAY = 2;
static const UBaseType_t PRIO_LOGGER  = 2;
static const UBaseType_t PRIO_NETWORK = 1;

// Laenge der Logger-Queue (gepufferte Samples, falls SD kurz blockiert)
static const uint32_t LOGGER_QUEUE_LEN = 8;

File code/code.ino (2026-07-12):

// ============================================================================
//  Raumluft-Qualitaet-Messung  -  ESP32-S3-Zero
//
//  Sensor:   SCD30  (CO2 / Temperatur / Feuchte, I2C - Sensirion-Lib)
//  Anzeige:  SSD1306 0,96" OLED (SPI) - Uhrzeit, IP, CO2/Temp/Feuchte + Bewertung
//  Uhr:      DS3231 RTC (I2C) + NTP-Synchronisation
//  Speicher: MicroSD (SPI) - CSV-Archiv, /history.json, statische Webdateien
//  Netzwerk: WLAN (STA mit AP-Fallback) + Async-Webserver
//
//  Architektur (FreeRTOS, Dual-Core):
//    Core 1 (Messkern):   SensorTask, DisplayTask, LoggerTask
//    Core 0 (Netzkern):   NetworkTask (+ AsyncTCP-Webserver-Task)
//
//  Geteilte, nicht-threadsichere Busse werden per Mutex serialisiert:
//    g_i2cMutex -> Wire (SCD30 + RTC)
//    g_spiMutex -> SD-SPI-Bus (Logger/Webserver); OLED hat eigenen HSPI-Bus
// ============================================================================
#include <Wire.h>
#include "config.h"
#include "Sync.h"
#include "Data.h"
#include "Sensor.h"
#include "AppTime.h"
#include "Storage.h"
#include "Display.h"
#include "Led.h"
#include "WebNet.h"

AppConfig     g_cfg;                 // globale Laufzeitkonfiguration
QueueHandle_t g_logQueue = nullptr;  // SensorTask -> LoggerTask

// SD-Auftraege an den LoggerTask
enum LogCmdType { CMD_LOG_CSV, CMD_SAVE_HISTORY };
struct LogCmd { LogCmdType type; Sample sample; };

// ---------------------------------------------------------------------------
//  Tasks
// ---------------------------------------------------------------------------

// BOOT-Taster (GPIO0) pruefen und bei langem Druck die SCD30-Kalibrierung ausloesen
static void handleCalibrationButton() {
  static uint32_t btnDownMs = 0;
  static bool     triggered = false;

  if (digitalRead(PIN_BOOT_BUTTON) == LOW) {          // gedrueckt (active low)
    if (btnDownMs == 0) {
      btnDownMs = millis();
    } else if (!triggered && (millis() - btnDownMs) >= CAL_HOLD_MS) {
      triggered = true;                               // pro Druck nur einmal
      dataSetMessage("Kalibriere...", 3000);
      bool ok = sensorForceCalibration(CO2_CALIBRATION_PPM);
      dataSetMessage(ok ? "Kalibriert!" : "Kal. Fehler", 4000);
      if (ok) ledConfirm();
    }
  } else {                                            // losgelassen -> zuruecksetzen
    btnDownMs = 0;
    triggered = false;
  }
}

// Core 1: Sensor lesen, Live-Wert + Verlauf + Ampel aktualisieren, Logs ausloesen
void sensorTask(void*) {
  uint32_t lastHistMs = 0, lastCsvMs = 0;
  Sample s;
  for (;;) {
    if (sensorRead(s)) {
      dataSetLatest(s);
      ledSetCo2(s.co2, s.valid);

      uint32_t nowMs = millis();

      // History-Punkt (Graph) + /history.json schreiben
      if (lastHistMs == 0 || (nowMs - lastHistMs) >= g_cfg.historyIntervalS * 1000UL) {
        lastHistMs = nowMs;
        dataPushHistory(s);
        LogCmd cmd = { CMD_SAVE_HISTORY, s };
        xQueueSend(g_logQueue, &cmd, 0);
      }
      // CSV-Archiv
      if (lastCsvMs == 0 || (nowMs - lastCsvMs) >= g_cfg.logIntervalS * 1000UL) {
        lastCsvMs = nowMs;
        LogCmd cmd = { CMD_LOG_CSV, s };
        xQueueSend(g_logQueue, &cmd, 0);
      }
    }
    handleCalibrationButton();
    vTaskDelay(pdMS_TO_TICKS(100));         // 100 ms -> Taster reagiert fluessig
  }
}

// Core 1: OLED regelmaessig neu zeichnen
void displayTask(void*) {
  for (;;) {
    StatusSnapshot snap;
    dataSnapshot(snap);
    displayRender(snap);
    vTaskDelay(pdMS_TO_TICKS(1000));
  }
}

// Core 1: SD-Auftraege abarbeiten + SD-Karte ueberwachen (I/O isoliert vom Sensor)
void loggerTask(void*) {
  LogCmd cmd;
  for (;;) {
    // Auf Auftrag warten, aber spaetestens alle 5 s aufwachen fuer den SD-Check.
    if (xQueueReceive(g_logQueue, &cmd, pdMS_TO_TICKS(5000)) == pdTRUE) {
      if (cmd.type == CMD_LOG_CSV) {
        storageLogSample(cmd.sample);
      } else {                              // CMD_SAVE_HISTORY
        StatusSnapshot snap;
        dataSnapshot(snap);                 // Datenmutex (kurz), dann...
        storageSaveHistory(snap);           // ...SD-Mutex -> keine Verschachtelung
      }
    }
    // Herausziehen/Wiedereinstecken der Karte erkennen und Status melden.
    dataSetSd(storageCheck());
  }
}

// Core 0: WLAN aufbauen, NTP synchronisieren, Webserver betreiben & ueberwachen
void networkTask(void*) {
  networkConnect();

  if (networkStaConnected()) {
    bool synced = timeSyncNtp(10000);
    dataSetRtc(timeRtcPresent(), synced);
  }
  networkStartServer();

  uint32_t lastSyncMs = millis();
  const uint32_t RESYNC_MS = 6UL * 3600UL * 1000UL;   // alle 6 h
  for (;;) {
    networkLoop();
    if (networkStaConnected() && (millis() - lastSyncMs) >= RESYNC_MS) {
      lastSyncMs = millis();
      bool synced = timeSyncNtp(5000);
      dataSetRtc(timeRtcPresent(), synced);
    }
    vTaskDelay(pdMS_TO_TICKS(2000));
  }
}

// ---------------------------------------------------------------------------
//  Setup
// ---------------------------------------------------------------------------
void setup() {
  Serial.begin(115200);
  delay(300);
  Serial.println(F("\n=== Raumluft-Qualitaet-Messung (ESP32-S3, FreeRTOS) ==="));

  // 1) Synchronisationsobjekte VOR jeglichem Buszugriff anlegen
  syncBegin();
  dataBegin();

  // 2) Busse starten
  //    I2C (gemeinsam fuer SCD30 + RTC)
  Wire.begin(PIN_I2C_SDA, PIN_I2C_SCL);
  Wire.setClock(100000);          // 100 kHz: vertraeglich mit SCD30-Clock-Stretching
  Wire.setTimeOut(100);           // laengeres Timeout fuer Clock-Stretching (ms)
  //    SPI (gemeinsam fuer SD + OLED) - einmal mit Pins starten
  g_spi.begin(PIN_SPI_SCK, PIN_SPI_MISO, PIN_SPI_MOSI);

  // 3) Peripherie
  pinMode(PIN_BOOT_BUTTON, INPUT_PULLUP);   // Taster active low (HIGH = nicht gedrueckt)
  ledBegin();
  ledStartupTest();                         // Boot-Selbsttest der LEDs (Verdrahtung)
  ledSetCo2(0, false);

  if (storageBegin()) {
    storageLoadConfig();      // SD zuerst -> Konfig laden
    storageLoadHistory();     // gespeicherten Verlauf in den Ringpuffer laden
  }
  dataSetSd(storageOk());

  bool rtc = timeBegin();                     // nutzt TZ aus der Konfig
  dataSetRtc(rtc, false);

  sensorBegin();

  if (displayBegin()) {
    if (!storageOk()) {
      // SD fehlt/defekt -> deutlich anzeigen (ohne SD gibt es auch kein Webinterface)
      displayShowBoot("!! KEINE SD-KARTE", "fehlt oder defekt");
      delay(3000);            // kurz stehen lassen, damit es auffaellt
    } else {
      displayShowBoot("Raumluft-Messung", "starte...");
    }
  }

  // 4) Queue + Tasks
  g_logQueue = xQueueCreate(LOGGER_QUEUE_LEN, sizeof(LogCmd));

  xTaskCreatePinnedToCore(sensorTask,  "sensor",  STACK_SENSOR,  nullptr, PRIO_SENSOR,  nullptr, CORE_MEASURE);
  xTaskCreatePinnedToCore(displayTask, "display", STACK_DISPLAY, nullptr, PRIO_DISPLAY, nullptr, CORE_MEASURE);
  xTaskCreatePinnedToCore(loggerTask,  "logger",  STACK_LOGGER,  nullptr, PRIO_LOGGER,  nullptr, CORE_MEASURE);
  xTaskCreatePinnedToCore(networkTask, "network", STACK_NETWORK, nullptr, PRIO_NETWORK, nullptr, CORE_NETWORK);

  Serial.println(F("[Setup] Tasks gestartet."));
}

// Die eigentliche Arbeit passiert in den Tasks; loop() bleibt leer.
void loop() {
  vTaskDelay(pdMS_TO_TICKS(1000));
}

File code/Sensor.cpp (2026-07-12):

// ============================================================================
//  Sensor.cpp  -  Sensirion I2C SCD30
// ============================================================================
#include "Sensor.h"
#include "AppTime.h"
#include "Sync.h"
#include <SensirionI2cScd30.h>

namespace {
  SensirionI2cScd30 s_scd30;
  bool s_ok = false;

  void logErr(const char* what, int16_t err) {
    char msg[64];
    errorToString(err, msg, sizeof(msg));
    Serial.printf("[Sensor] %s: %s\n", what, msg);
  }
}

bool sensorBegin() {
  // begin() speichert nur Wire-Referenz + Adresse (kein Buszugriff).
  s_scd30.begin(Wire, SCD30_I2C_ADDR_61);

  // Mess-Takt aus der Konfig (config.json: "scd30_interval_s"), auf 2..1800 s begrenzt
  uint16_t interval = g_cfg.scd30IntervalS;
  if (interval < 2)    interval = 2;
  if (interval > 1800) interval = 1800;

  I2cGuard g;   // ab hier echte I2C-Kommandos
  s_scd30.stopPeriodicMeasurement();          // evtl. laufende Messung stoppen
  s_scd30.softReset();
  delay(2000);                                 // SCD30 braucht ~2 s nach Reset

  int16_t err = s_scd30.setMeasurementInterval(interval);
  if (err) { logErr("setMeasurementInterval", err); }

  err = s_scd30.startPeriodicMeasurement(0);   // 0 = keine Druckkompensation
  if (err) { logErr("startPeriodicMeasurement", err); s_ok = false; return false; }

  // Hinweis: Der Temperatur-Offset wird in sensorRead() per Software abgezogen
  // (der Hardware-Offset des SCD30 greift bei manchen Sensoren nicht zuverlaessig).
  Serial.printf("[Sensor] SCD30 ok, Intervall %us, Temp-Offset %.1f C (Software)\n",
                interval, g_cfg.tempOffsetC);
  s_ok = true;
  return true;
}

bool sensorRead(Sample& out) {
  if (!s_ok) return false;
  {
    I2cGuard g;
    uint16_t ready = 0;
    if (s_scd30.getDataReady(ready) != 0 || ready == 0) return false;
    if (s_scd30.readMeasurementData(out.co2, out.temp, out.hum) != 0) return false;
  }
  out.temp -= g_cfg.tempOffsetC;   // Software-Offset (Eigenerwaermung des SCD30)
  out.epoch = timeNowEpoch();   // liest RTC (eigener I2C-Guard darin)
  out.heap  = ESP.getFreeHeap();
  out.valid = (out.co2 > 0.0f && out.co2 < 40000.0f);
  return out.valid;
}

bool sensorForceCalibration(uint16_t ppm) {
  if (!s_ok) return false;
  I2cGuard g;
  int16_t err = s_scd30.forceRecalibration(ppm);
  if (err) { logErr("forceRecalibration", err); return false; }
  Serial.printf("[Sensor] Forced Recalibration auf %u ppm gesetzt.\n", ppm);
  return true;
}

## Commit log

2026-07-07 added License and option to use 1 led or more
    [schaltplan.kicad_pcb, schaltplan.kicad_sch]
2026-07-12 added offset temperature as float
2026-07-12 patched Temperature offset
2026-07-12 precondition to switch with old Board to i2c
